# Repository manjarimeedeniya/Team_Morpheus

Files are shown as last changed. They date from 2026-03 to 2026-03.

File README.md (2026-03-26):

# Weighing Scale Using Load Cells

**EN2091 Analog Project** — Department of Electronic and Telecommunication Engineering, University of Moratuwa, Sri Lanka

---

## 👥 Team Morpheus 

| Name | GitHub Link |
|---|---|
| Gunarathne K.T.M.B | https://github.com/ThidaswinGunarathna |
| Jayaweera N.S | https://github.com/NisalJayaweera |
| Meedeniya M.M.H | https://github.com/manjarimeedeniya |
| Ranawaka R.A.C.D | https://github.com/chaniruranawaka |

---

## 📋 Project Overview

An electronic weighing scale designed and implemented using a **strain gauge load cell**. The system captures the low-level differential voltage produced by the load cell, amplifies and filters it through an analog signal conditioning circuit, and displays the corresponding weight on a **16×2 LCD screen** via an ESP32 microcontroller.

**Key Specifications:**
- Maximum measuring capacity: **10 kg**
- Power input: **230V AC mains**
- Full-scale output voltage: **3V** (at 10 kg)
- Display: **16×2 LCD** (via I²C interface)
- Microcontroller: **ESP-WROOM-32E (ESP32)**

---

## 📸 Final Product
<p align="center">
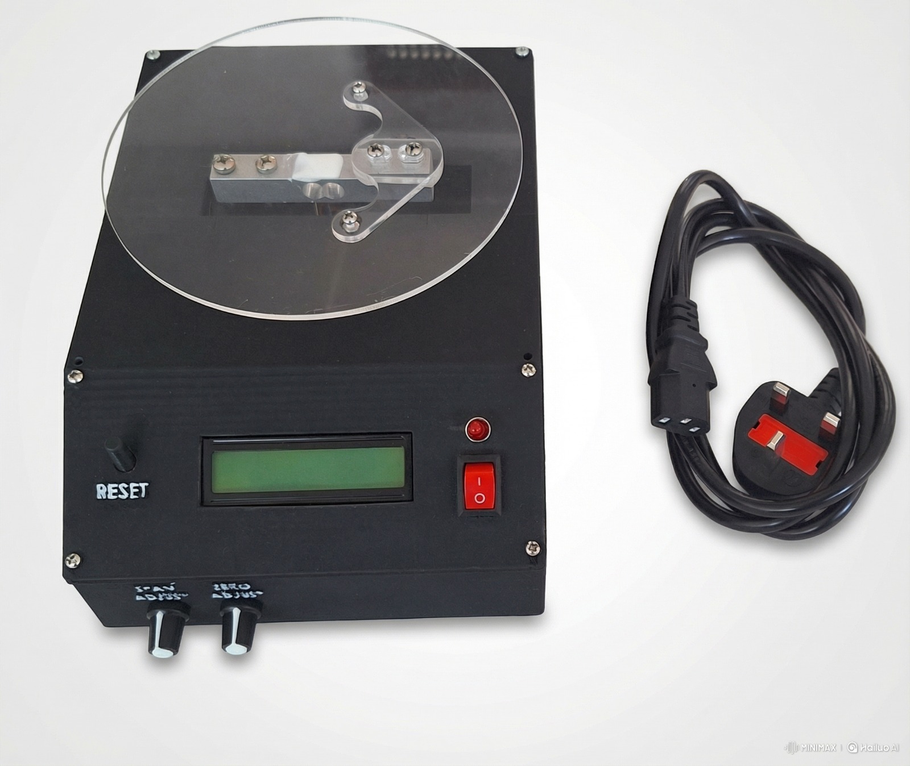
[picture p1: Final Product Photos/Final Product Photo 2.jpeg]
Weighing Scale - Final Product
  
</p>

---

## 🏗️ System Architecture

```
230V AC Supply
      │
      ▼
Step-Down Transformer (230V → 13.5V AC)
      │
      ▼
Power Supply Circuit (Delon Doubler + Regulators)
      │
      ├──► +12V, -12V (for op-amps & load cell excitation)
      ├──► +5V  (for LCD)
      └──► +3.3V (for ESP32)

Load Cell (Wheatstone Bridge)
      │
      ▼
INA114 Instrumentation Amplifier (Gain ≈ 100)
      │
      ▼
Zero Adjust Circuit (TL084 op-amp + potentiometer)
      │
      ▼
Span Adjust Circuit (TL084 op-amp, variable gain)
      │
      ▼
3rd Order Sallen-Key Low-Pass Filter (10 Hz cutoff, TL072)
      │
      ▼
ESP32 ADC → Weight Calculation → 16×2 LCD Display
```

---

## ⚙️ Circuit Design

### Load Cell
- Type: Strain-gauge based, Wheatstone bridge configuration
- Capacity: 20 kg (used up to 10 kg)
- Rated output: 2.0 ± 0.15 mV/V
- Excitation voltage: 12V DC

### Amplifier Circuit
| Stage | Component | Purpose |
|---|---|---|
| Instrumentation Amplifier | INA114 | Amplifies differential load cell output (gain ≈ 100), high CMRR (~115 dB) |
| Zero Adjust | TL084 + 100kΩ potentiometer | Cancels offset voltage at zero load |
| Span Adjust | TL084 + 100kΩ potentiometer | Calibrates full-scale output to 3V at 10 kg |
| Low-Pass Filter | TL072 (3rd order Sallen-Key) | Cuts off noise above 10 Hz |

### Power Supply Circuit
| Regulator | Output | Powers |
|---|---|---|
| LM7812 | +12V | Load cell, INA114, op-amps |
| LM7912 | -12V | Op-amps (dual supply) |
| LM7805 | +5V | LCD display |
| AMS1117 | +3.3V | ESP32 chip |

The Delon Doubler circuit is used to generate the dual-supply (±) voltage from the single-rail transformer output.

---

## 🧰 Components List

### Amplifier Circuit
| Component | Quantity |
|---|---|
| INA114 Instrumentation Amplifier IC | 1 |
| TL084 Quad Op-Amp IC | 1 |
| TL072 Dual Op-Amp IC | 1 |
| 470Ω Resistor | 1 |
| 10kΩ Resistors | 8 |
| 100kΩ Resistor | 1 |
| 110kΩ Resistor | 1 |
| 11kΩ Resistor | 1 |
| 33kΩ Resistor | 1 |
| 100kΩ Variable Resistors (Potentiometers) | 2 |
| 0.1µF Capacitors | 5 |
| 0.68µF Capacitor | 1 |
| 1.5µF Capacitor | 1 |
| Push Buttons | 2 |
| JST Wire Connectors 2.54mm (4-pin) | 3 |
| JST Wire Connectors 2.54mm (5-pin) | 1 |

### Power Supply Circuit
| Component | Quantity |
|---|---|
| 230V AC to 13.5V AC Step-Down Transformer | 1 |
| 1N4007 Diodes | 2 |
| 50V 1000µF Capacitors | 2 |
| 50V 470µF Capacitors | 2 |
| 50V 100µF Capacitors | 2 |
| 50V 10µF Capacitors | 2 |
| LM7812 +12V Regulator | 1 |
| LM7912 -12V Regulator | 1 |
| LM7805 +5V Regulator | 1 |
| AMS1117 3.3V Regulator | 1 |
| Switch | 1 |
| LED | 1 |
| JST Wire Connectors 2.54mm (2-pin) | 3 |
| JST Wire Connectors 2.54mm (5-pin) | 1 |

### Other Components
| Component | Quantity |
|---|---|
| 20kg Strain-Gauge Load Cell | 1 |
| ESP-WROOM-32E Microcontroller | 1 |
| 16×2 LCD Display | 1 |
| IIC/I²C Serial Interface Module for LCD | 1 |
| 3-pin AC Power Base | 1 |
| Power Cable | 1 |

---

---

## 🔧 Calibration Procedure

1. **Zero Adjustment** — With no load on the scale, adjust the zero-adjust potentiometer until the LCD reads `0.00 kg`.
2. **Span Adjustment** — Place a known 10 kg reference weight on the platform. Adjust the span-adjust potentiometer until the display reads `10.00 kg`.
3. The system is now calibrated across the full measurement range.

---

## 💻 Firmware

The ESP32 firmware reads the analog voltage output from the signal conditioning circuit via its built-in ADC, applies the calibration mapping, and sends the weight value to the 16×2 LCD over I²C.

**Upload Instructions:**
1. Install the [Arduino IDE](https://www.arduino.cc/en/software) and add ESP32 board support.
2. Install the `LiquidCrystal_I2C` library via the Library Manager.
3. Open `firmware/main.ino`, select your board (`ESP32 Dev Module`) and COM port.
4. Upload the sketch.

---

## 🚧 Challenges Encountered

- **Capacitor availability** — 0.68µF and 1.5µF electrolytic capacitors were unavailable locally. Ceramic equivalents were used, but their lead spacing required manual wire extensions to fit the PCB footprint.
- **Electromagnetic interference** — After full assembly, the amplifier output showed an unexpected ~60V peak-to-peak sine wave. This was traced to electromagnetic radiation from the mains transformer coupling into nearby signal wires. The fix involved additional transformer shielding with a metal plate and shortening signal wire runs.
- **Platform deformation** — The initial wooden weighing platform deformed under load and made contact with the base, introducing measurement errors. It was replaced with a rigid acrylic plate with a larger clearance gap.

---

## 🔭 Future Improvements

- **Battery operation** — Replace mains power with a low-power design for portability.
- **Wireless connectivity** — Add Bluetooth or Wi-Fi (ESP32 already supports this) for remote monitoring and data logging to a mobile app or PC.

---

## 👨‍💼 Contributions

| Member | Contributions |
|---|---|
| Gunarathne K.T.M.B  | ESP32 firmware, LCD integration, soldering, assembly, component selection |
| Jayaweera N.S  | PCB design, soldering, assembly, component selection |
| Meedeniya M.M.H  | Circuit design, enclosure design, assembly, component selection |
| Ranawaka R.A.C.D  | Enclosure span design, soldering, assembly, component selection |

---

## 🙏 Acknowledgements

We sincerely thank **Dr. Sampath Perera** and supervisor **Mr. Viruthshaan** for their guidance throughout the project. We also appreciate the feedback from **Dr. Jayathu Samarawickrama**, **Dr. Pranjeevan Kulasingham**, **Dr. Wageesha N. Manamperi**, and **Mr. Lathika Wathsara** during the project evaluation. Thanks to the academic and non-academic staff of the ENTC Department, University of Moratuwa, for their support and facilities.

---

## 📚 References

1. INA114 Datasheet — https://www.alldatasheet.com/datasheet-pdf/view/847617/TI1/INA114.html
2. TL084 Datasheet — https://www.alldatasheet.com/datasheet-pdf/view/25385/STMICROELECTRONICS/TL084.html
3. TL072 Datasheet — https://www.alldatasheet.com/datasheet-pdf/view/28775/TI/TL072.html
4. LM7812 Datasheet — https://www.alldatasheet.com/datasheet-pdf/pdf/838008/TI1/LM7812.html

---

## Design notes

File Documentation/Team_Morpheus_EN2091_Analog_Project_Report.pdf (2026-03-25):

## Department of Electronic and Telecommunication Engineering

## University of Moratuwa

## Sri Lanka

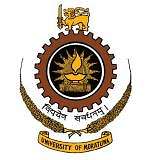
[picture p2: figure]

## EN2091 Analog Project

## Weighing Scale Using Load Cells

## Group 10 - Team Morpheus

Group Members:

### 230203G - Gunarathne K.T.M.B 230300C - Jayaweera N.S 230407K - Meedeniya M.M.H 230526A - Ranawaka R.A.C.D

Date: 11th

### of December 2025

WEIGHING SCALE USING LOAD CELL | GROUP 10
- 2 -

## Abstract

This project presents the design and implementation of an electronic weighing scale using a strain gauge load cell for weight measurement. The low-level differential voltage which is produced by the load cell is proportional to the applied load, and it is amplified using an operational amplifier-based signal conditioning circuit. An active filter is employed to reduce noise and improve measurement stability. The conditioned signal is processed, and the corresponding weight value is displayed on a 16×2 LCD screen through a serial interface. The developed system can measure weights up to 10 kg with satisfactory accuracy. This project demonstrates practical aspects of sensor interfacing, analog signal amplification, noise filtering, and display integration.

- 3 -

## Contents

### 1. Introduction | - 4 -

### 2. System Architecture | - 4 -

Functional Block Diagram | - 4 -
Load Cell | - 4 -
Amplifier Circuit | - 5 -
Power Supply Circuit | - 6 -

### 3. Component Selection | - 7 -

Components for the Amplifier Circuit | - 8 -
Components for the Power Supply Circuit | - 9 -
Other Components | - 9 -

### 4. PCB Design | - 10 -

Amplifier Circuit | - 10 -
Power Supply Circuit | - 11 -

### 5. Enclosure Design | - 12 -

### 6. Challenges Encountered | - 14 -

### 7. Future Works | - 15 -

### 8. Conclusion | - 15 -

### 9. Contribution of Group Members | - 16 -

### 10. Acknowledgement | - 16 -

### 11. References | - 16 -

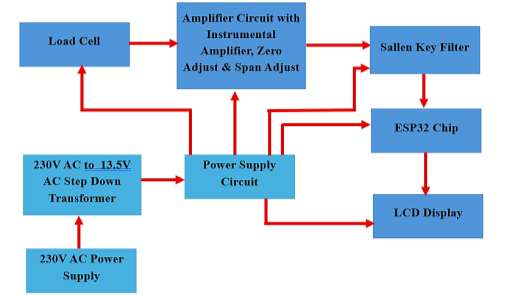
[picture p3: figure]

- 4 -

## Introduction

In this project, an electronic weighing scale is designed and developed using a strain-gauge-based load cell with a maximum measuring capacity of 10 kg. The system operates using a 230 V AC mains power supply. This mains voltage is stepped down to 13.5 V AC through a transformer and then rectified and regulated to provide the required DC voltages for different circuit components. The small electrical signal generated by the load cell is amplified and processed using a microcontroller, which calculates the corresponding weight and displays it on a 16×2 LCD screen. Additionally, a protective enclosure is designed to house all electronic components securely.

## System Architecture

Functional Block Diagram

Figure 1 : Functional Block Diagram

Load Cell

This weighing scale using a strain gauge–based load cell sensor operates by converting the applied mechanical force into an electrical signal
and processing it to obtain a readable weight value.
When an object is placed on the circular platform,
the applied weight is transferred to the load cell. The load cell consists of strain gauges arranged in a Wheatstone bridge (Figure 2)configuration. As
the load is applied, the strain gauges deform
slightly, causing a proportional change in their

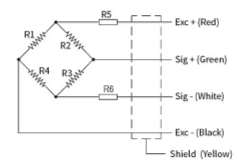
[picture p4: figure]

electrical resistance. This resistance variation | Figure 2 : Wheatstone Bridge
| in Load Cell Sensor

- 5 -

produces a small differential DC voltage signal corresponding to the applied weight. The output signal from the load cell is fed into an amplifier circuit.

Amplifier Circuit
Instrumentation Amplifier

This is the first stage of the amplifier circuit, and when the output from the load cell is fed into the amplifier circuit, this is used to amplify low-level differential voltage output generated by the load cell. In our system this has a gain around 100. Its high input impedance and high CMRR enable

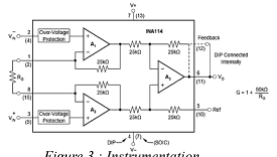
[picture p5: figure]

accurate signal amplification while minimizing noise.

Zero Adjust Circuit
The zero adjust circuit is incorporated after the instrumentation amplifier stage to eliminate offset errors and ensure accurate weight measurement. Even when no load is applied to the load cell, small offsets can appear at the output due to strain gauge mismatch, amplifier input offset voltage, temperature variations, or mechanical stresses. If not corrected, these offsets would cause the weighing scale to display a non-zero value at no load.

In our design, the zero adjustment is implemented
using an operational amplifier (TL084) configured
with a variable reference voltage derived from a potentiometer connected between +12 V and −12
V. The wiper of the potentiometer provides an adjustable DC voltage, which is fed into the summing node of the op-amp through equal-value
resistors (10 kΩ). This arrangement allows a small
positive or negative DC offset to be added to or

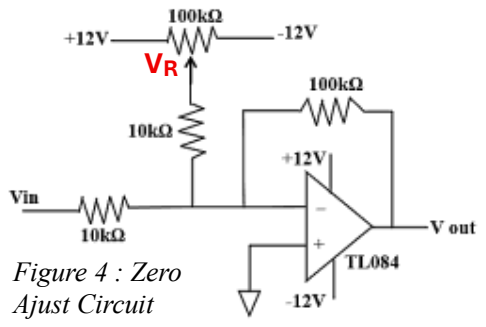
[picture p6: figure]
Figure 4 : Zero Ajust Circuit

subtracted from the amplified load cell signal. By adjusting the potentiometer, the output of this stage can be precisely set to zero when the weighing platform is unloaded.

Equations:

Vin
10×10³ +

VR
10 ×10³ =

Vout
100 ×10³

Vin + VR =

Vout
10

Zero adjust is performed when the load cell is unloaded. So the Vout should become theoritically zero after zzero adjust is performed. So,

VR = −Vin

Figure 3 : Instrumentation Amplifier Circuit Inside the Instrumentation Amplifier IC

- 6 -

Span Adjust Circuit

The span adjust circuit is used to calibrate the gain of the weighing scale system so that the output voltage corresponds accurately to the applied load over the full measurement range. In our design, the span adjustment is implemented using an operational amplifier (TL084) configured with a variable gain. A potentiometer is incorporated in the feedback path of the amplifier, allowing the overall gain of this stage to
be finely adjusted. During calibration, a known
10kg weight is placed on the load cell, and the
potentiometer is adjusted until the system output corresponds to the correct weight value on the display. This ensures that the full-scale output voltage of the signal conditioning circuit accurately represents the maximum rated load of the weighing scale. In our case the full scale output voltage has been chosen as 3V for maximum rated load 10kg, since this output needs to be fed to the microcontroller.
Equation : Vout =

1
20

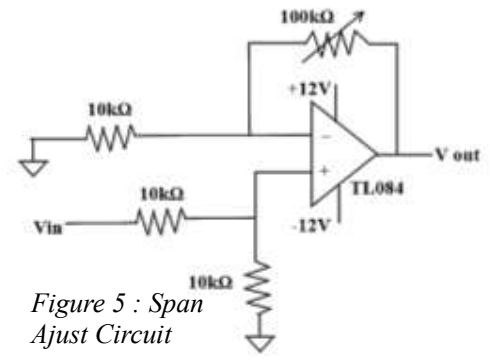
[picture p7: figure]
Figure 5 : Span Ajust Circuit

(Resistance of tℎe variable resistor + 10) Vin

Filter Circuit
In the end of the amplifier circuit, a 3rd order Sallen Key low pass filter with a 10Hz cutoff is implemented. The primary function of this filter
is to allow low-frequency signals corresponding
to actual weight changes to pass through while
attenuating high-frequency noise components. Since weight variations occur slowly, high-frequency signals do not contain useful information and must be removed.

ESP32 Chip & LCD Display

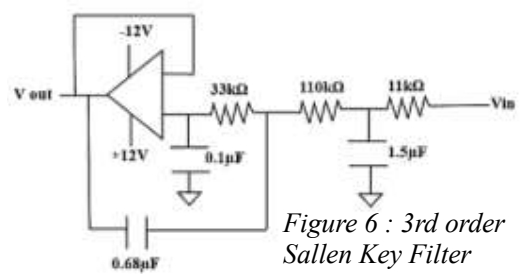
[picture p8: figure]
Figure 6 : 3rd order Sallen Key Filter

The amplified and filtered signal is read by the microcontroller’s analog-to-digital converter. Using the programmed calibration parameters and conversion algorithms, the microcontroller processes the signal and converts it into a corresponding weight value. This calculated weight is then displayed on an LCD screen.

Power Supply Circuit

The 13.5(RMS) V AC output from the transformer is fed to the power supply circuit input. The voltage goes through the Delon Doubler circuit. Here Delon Doubler circuit has been used to get dual supply voltage. Then the regulators regulate the voltage to +12V, -12V, +5V and +3.3V, and then the voltage is distributed to the components.

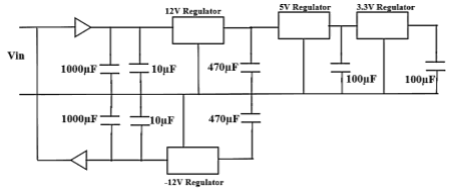
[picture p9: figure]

- 7 -

Figure 7 : Power Supply Circuit

## Component Selection

Components for the Amplifier Circuit | Components for the Power Supply Circuit | Other Components
INA 114 Instrumentation Amplifier – 1 | 230V AC to 13.5 V AC Step Down Transformer | 20kg Load Cell
TL084 OpAmp IC – 1 | 1N4007 Diodes – 2 | ESP-WROOM-32E microcontroller
TL072 OpAmp IC – 1 | 50V 1000µF Capacitors – 2 | 16 x 2 LCD Display
470Ω Resistor – 1 | 50V 470µF Capacitors – 2 | IIC/I2C/TWI/SPI Serial Interface Board Module Port for 1602 LCD Display
100kΩ variable resistors -2 | 50V 100µF Capacitors – 2 | 3 pin AC power base
10kΩ resistors – 8 | 50V 10µF Capacitors – 2 | Power cable
100kΩ resistors – 1 | LM7812 12V Regulator – 1
110kΩ resistors – 1 | LM7912 -12V Regulator – 1
11kΩ resistors – 1 | LM7805 5V Regulator – 1
33kΩ resistors – 1 | AMS1117 3.3V Regulator – 1
0.1µF Capacitors – 5 | Switch
0.68µF Capacitors – 1 | LED
1.5µF Capacitors – 1 | JST Wire connectors 2.54mm with socket 5 pin – 1
Push buttons – 2 | JST Wire connectors 2.54mm with socket 2 pin – 3

JST Wire connectors 2.54mm with socket 4 pin – 3

JST Wire connectors 2.54mm with socket 5 pin – 1

Table 1 : Used Component List

- 8 -

Components for the Amplifier Circuit

INA 114 Instrumentation Amplifier IC

When the Wheatstone bridge of load cell sensor outputs the voltage difference between the two nodes, this instrumentation amplifier is used to amplify only the voltage difference between V+ and V- and rejects everything common to both. According to the datasheet, this has an extremely high common mode rejection ratio which is around 115 dB (1). This has a high input impedance, so loading the bridge of load cell sensor is negligible. Gain of this amplifier can be changed in wide range, so you can choose a better gain. Such characteristics of the amplifier ensure accurate and stable weight measurement.

TL084 OpAmp IC

This is a quad JFET-input operational amplifier IC. This IC reduces the complexity of the PCB, having 4 op amp in one IC. According to the datasheet, since this has a high input impedance and a low input bias current, which is around 65pA, this creates no voltage across the resistors. Because such voltage changes can affect the sensitive signals from the load cell sensor. So, these characteristics help to ensure accurate weight measurement. (2) In our design this is used for the inverting amplifier, zero adjust system and span adjust system.

TL072 OpAmp IC

This is a dual JFET-input operational amplifier that is very commonly used in active filter circuits. In our design this opamp is used for the 3rd order Sallen key filter circuit. Since this has a typical input noise of 18 nV/√Hz, it filters small signals, and low noise prevents corrupting the amplified load-cell output. (3)

470Ω Resistor

This resistor is used to get a nearly 100 gains from the instrumentation amplifier .

100kΩ variable resistors

The span adjusts and zero adjust circuits are mainly controlled using these resistors. For this resistance, a big current does not flow through these resistors. In the zero adjust, if the resistor values are very low, it will load the opamp node, and then voltage will be pulled strongly, there will be sudden drastic changes in voltage when performing calculations and calibration will be unstable. If resistance is too large, thermal drift increases and becomes noisy. In the span adjust, if the resistance of the variable resistor is too low, it will be closer

- 9 -

to the other resistor values in the circuit and will high affect to the change of the gain. But for this value amplifier stays linear and the calibration becomes more stable.

Components for the Power Supply Circuit

230V AC to 13.5 V AC Step Down Transformer

For LM7812, the minimum input voltage to maintain linear regulation is 14.6V (4). Mainly to satisfy that requirement, this transformer was selected.

LM7812 12V Regulator & LM7912 negative 12V Regulator

These two regulators are used to give a +12V and -12V input for load cell, INA 114, Zero Adjust, TL084 and TL072 ICs.

LM7805 5V Regulator

This regulator is used to give a +5V input to LCD display.

AMS1117 3.3V Regulator

This regulator is used to give a +3.3V input to esp32 chip.

Other Components

Load Cell

In this project, a strain-gauge type load cell with 20kg maximum capacity was used. Its Rated output is 2.0±0.15(MV/V). Since its recommended excitation voltage is 10~15 V, in our product excitation voltage is given as 12V.

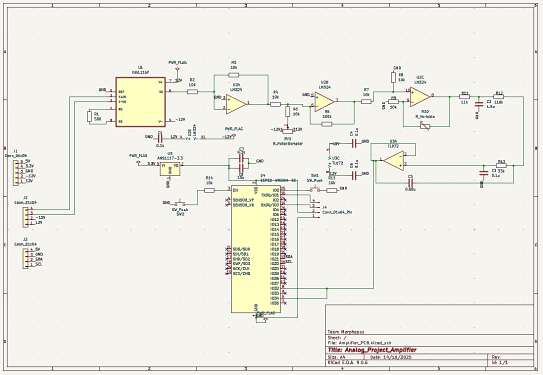
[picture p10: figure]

- 10 -

### 16 x 2 LCD Display

LCD Display is used to display the weight value in the screen. Weight is displayed in kilograms.

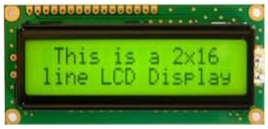
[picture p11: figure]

IIC/I2C/TWI/SPI Serial Interface Board Module Port for 1602 LCD Display

The IIC/I²C/TWI serial interface board for a 1602 LCD is used to enable serial communication between a microcontroller and the LCD display, reducing the number of required I/O pins and simplifying the hardware interface.

## PCB Design

Amplifier Circuit

Schematic & Software Designs

Figure 8 : Amplifier Circuit Schematic

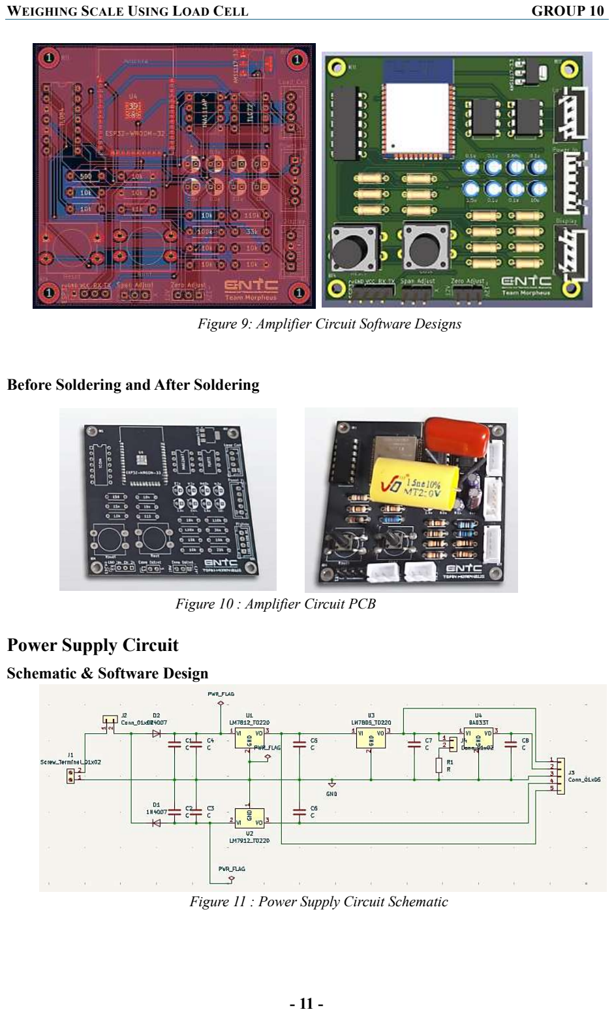
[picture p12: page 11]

- 11 -

Before Soldering and After Soldering

Power Supply Circuit

Schematic & Software Design

Figure 9: Amplifier Circuit Software Designs

Figure 10 : Amplifier Circuit PCB

Figure 11 : Power Supply Circuit Schematic

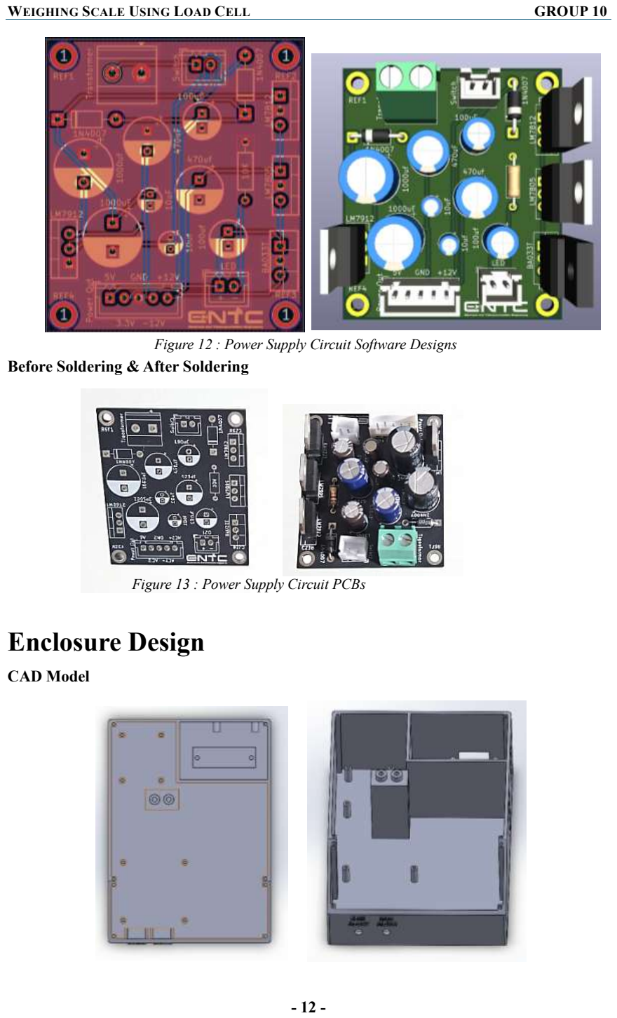
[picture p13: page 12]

- 12 -

Before Soldering & After Soldering

## Enclosure Design

CAD Model

Figure 12 : Power Supply Circuit Software Designs

Figure 13 : Power Supply Circuit PCBs

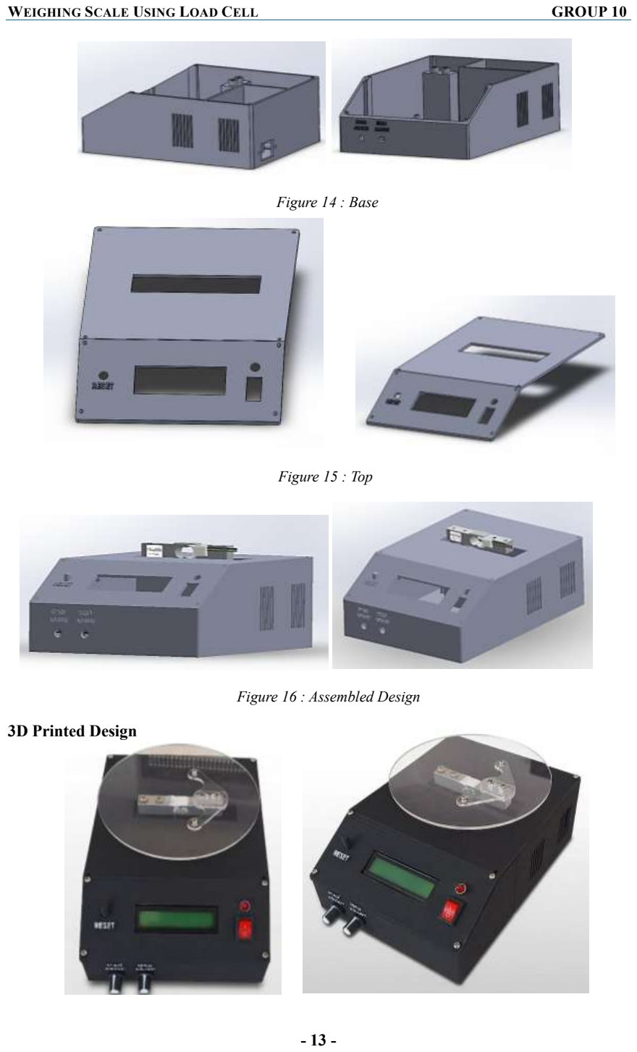
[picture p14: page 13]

- 13 -

3D Printed Design

Figure 14 : Base

Figure 15 : Top

Figure 16 : Assembled Design

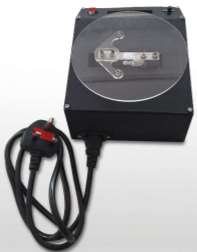
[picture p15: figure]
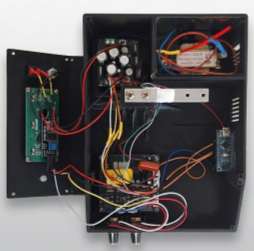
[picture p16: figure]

- 14 -

## Challenges Encountered

- During the implementation of the circuit, 0.68 µF and 1.5 µF electrolytic capacitors were not readily available in the local Sri Lankan market. As an alternative, ceramic capacitors with equivalent capacitance values were selected to proceed with the project without delay. However, the terminal thickness and lead spacing of the ceramic capacitors were not compatible with the PCB design. To overcome this issue, insulated connecting wires were soldered to the capacitor terminals, and these wires were then carefully soldered onto the PCB.
- During the initial PCB testing conducted before assembling the product, the circuit produced the expected output. However, one day prior to the project evaluation, after assembling the complete system and performing the testing again, unexpected issue was observed. The output of the amplifier circuit appeared as a sine wave with an approximately 60 V peak-to-peak voltage, which was abnormal and not expected from the design.

At first, all the circuit connections and solder joints were carefully checked, but no faults were found. Suspecting a defective capacitor, a new PCB was soldered and tested, yet the same issue occurred. When the previously working PCB was powered again using the power supply, it no longer showed the expected voltage variation. At this stage, it was assumed that some components might have been damaged due to the excessive voltage.

As the issue could not be identified through repeated testing, guidance was obtained from Dr. Upeka Premaratne. After examining the setup, he suggested that the problem might be related to the transformer used in the power supply. According to his explanation, electromagnetic radiation from the transformer could have interfered with nearby signal wires, inducing unwanted currents.

Although the transformer had been placed in a separate section of the enclosure, it was advised to further shield the transformer using a metal plate and to minimize and shorten the signal wire lengths to reduce electromagnetic interference. However, due to

Figure 17 : 3D Printed & Assembled Enclosure

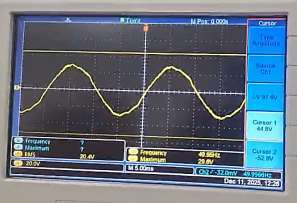
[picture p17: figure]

- 15 -

the use of ceramic capacitors with relatively thick terminals and attached connecting wires, it was difficult to significantly shorten the terminal lengths, and physical size differences further limited the effectiveness of this modification.

- Another challenge was related to the weighing platform structure. Initially, a wooden span was used, but it deformed under higher loads and touched the base of the setup, affecting measurement accuracy. To resolve this, the wooden span was replaced with an acrylic plate, and the gap between the platform and the base was increased to ensure that the load cell could bend freely without contacting any surface.

## Future Works

1.This design can be optimized for battery operation by using a low power component making the system portable.
2.Adding Bluetooth or Wi-Fi connectivity would allow wireless data transmission to a mobile phone or computer for monitoring and record keeping.

## Conclusion

In this project, an electronic weighing scale was successfully designed and implemented using a strain gauge load cell. The very small differential output produced by the load cell was amplified using an operational amplifier-based amplifier circuit, and unwanted noise was reduced using an active filter stage. The processed signal was then converted into a readable weight value and displayed clearly on a 16×2 LCD, providing a user-friendly interface. Overall, the project achieved its intended objectives and provided practical exposure to sensor interfacing, analog signal conditioning, and measurement system design.

Figure 18 : 60V(peak-peak) Sine wave that observed

- 16 -

## Contribution of Group Members

230203G Gunarathne K.T.M.B | Coding to display the measured weight using esp32 chip and LCD display, Soldering, Assembly, Component Selection
230300C Jayaweera N.S | PCB Designing, Soldering, Assembly, Component Selection
230407K Meedeniya M.M.H | Circuit Designing, Enclosure Designing, Assembly, Component Selection
230526A Ranawaka R.A.C.D | Enclosure Span Designing, Soldering, Assembly, Component Selection

## Acknowledgement

We would like to sincerely thank Dr. Sampath Perera and our supervisor Mr. Viruthshaan for their guidance, encouragement, and constant support throughout this project.We also appreciate the time and constructive feedback provided by Dr. Jayathu Samarawickrama, Dr. Pranjeevan Kulasingham, and Dr. Wageesha N. Manamperi,Mr. Lathika Wathsara during the evaluation of the project, which greatly helped us to improve its quality.Our heartfelt thanks go to the academic and non-academic staff of the ENTC Department for their assistance and for providing the necessary facilities during the project period. Finally, we are grateful to all our group members for their teamwork and commitment which were essential to the successful completion of this project.

## References

1. [Online] https://www.alldatasheet.com/datasheet-pdf/view/847617/TI1/INA114.html.
2. [Online] https://www.alldatasheet.com/datasheet-pdf/view/25385/STMICROELECTRONICS/TL084.html.
3. [Online] https://www.alldatasheet.com/datasheet-pdf/view/28775/TI/TL072.html.
4. [Online] https://www.alldatasheet.com/datasheet-pdf/pdf/838008/TI1/LM7812.html.

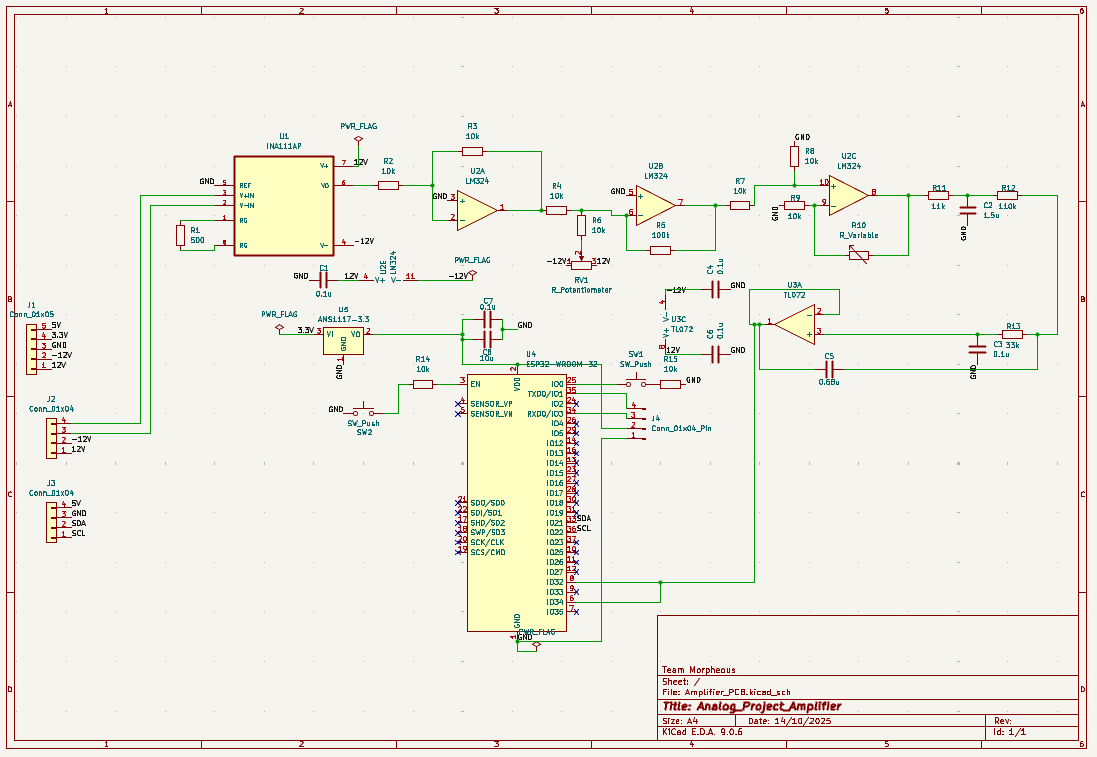
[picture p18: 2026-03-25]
PCB Files/Photos/Amplifier Schematic.png

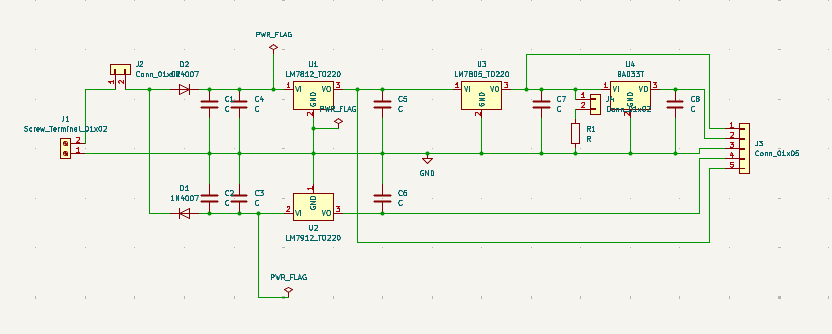
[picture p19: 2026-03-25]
PCB Files/Photos/Power Supply Schematic.png

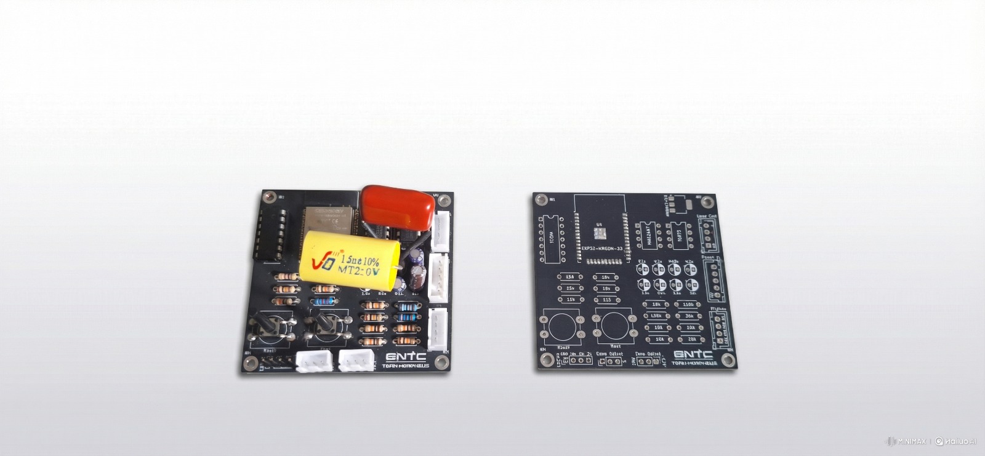
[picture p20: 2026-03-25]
PCB Files/Photos/Amplifier Circuit PCB.jpeg

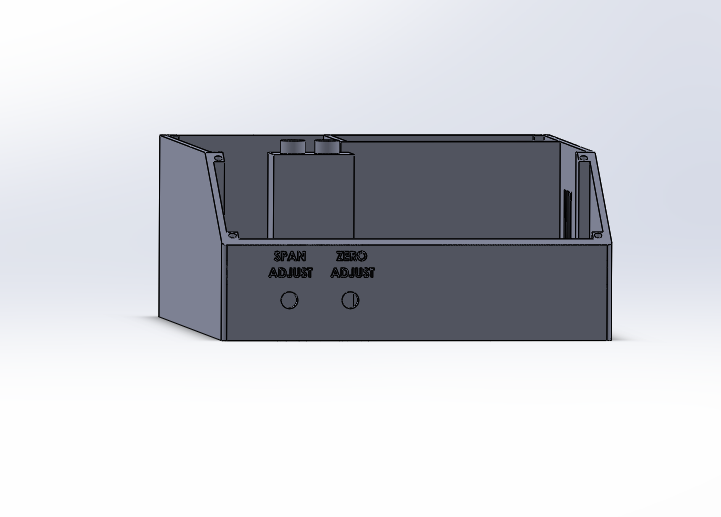
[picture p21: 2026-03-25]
Enclosure Files/Photos/Bottom_5 from SolidWorks.png

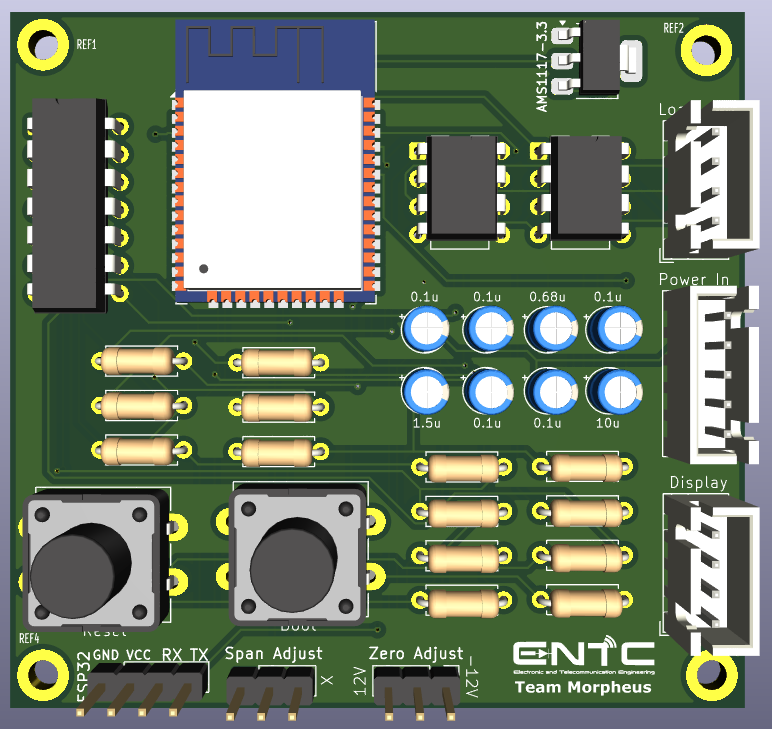
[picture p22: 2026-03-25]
PCB Files/Photos/Amplifier PCB 3D.png

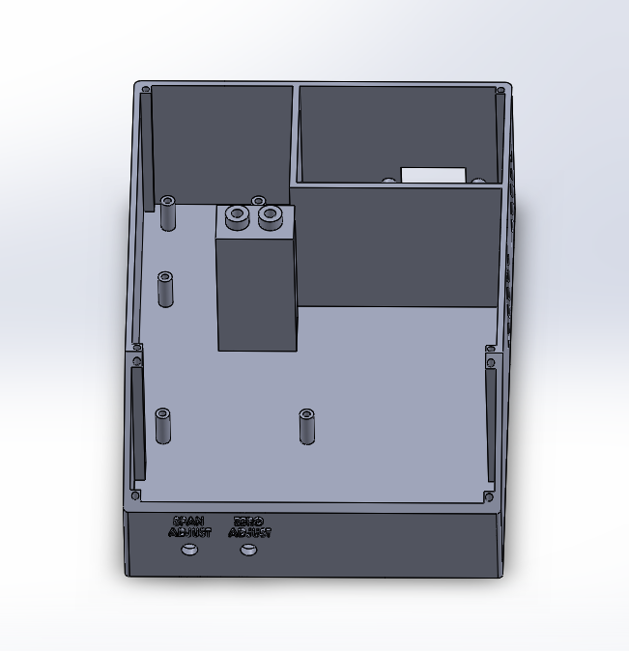
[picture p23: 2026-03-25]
Enclosure Files/Photos/Bottom_1 from SolidWorks.png

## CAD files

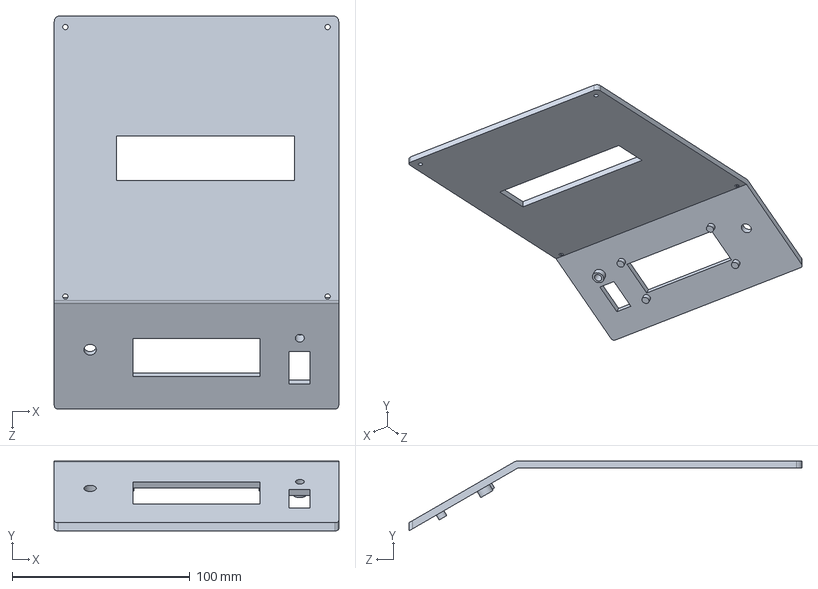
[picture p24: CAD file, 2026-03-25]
Enclosure Files/Top.SLDPRT
160.0 x 39.2 x 221.0 mm

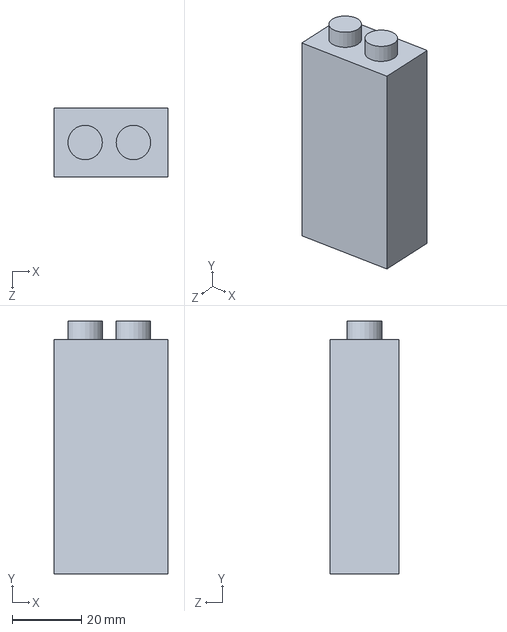
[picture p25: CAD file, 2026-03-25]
Enclosure Files/Loadcell Stand.SLDPRT
33.0 x 73.3 x 20.0 mm

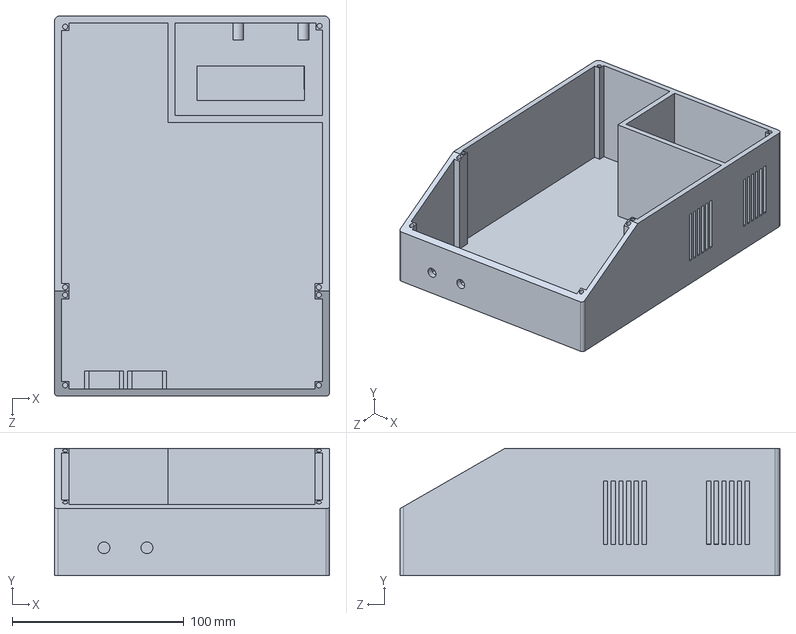
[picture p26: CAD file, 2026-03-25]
Enclosure Files/Base.SLDPRT
160.0 x 74.0 x 221.0 mm

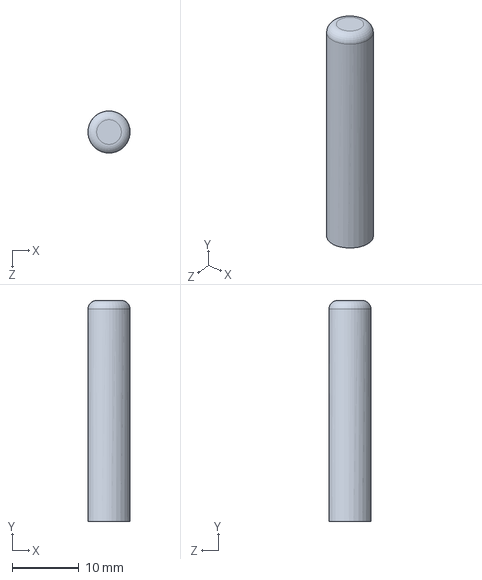
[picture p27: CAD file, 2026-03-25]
Enclosure Files/Tactile Switch Cap.SLDPRT
6.29 x 33.0 x 6.30 mm

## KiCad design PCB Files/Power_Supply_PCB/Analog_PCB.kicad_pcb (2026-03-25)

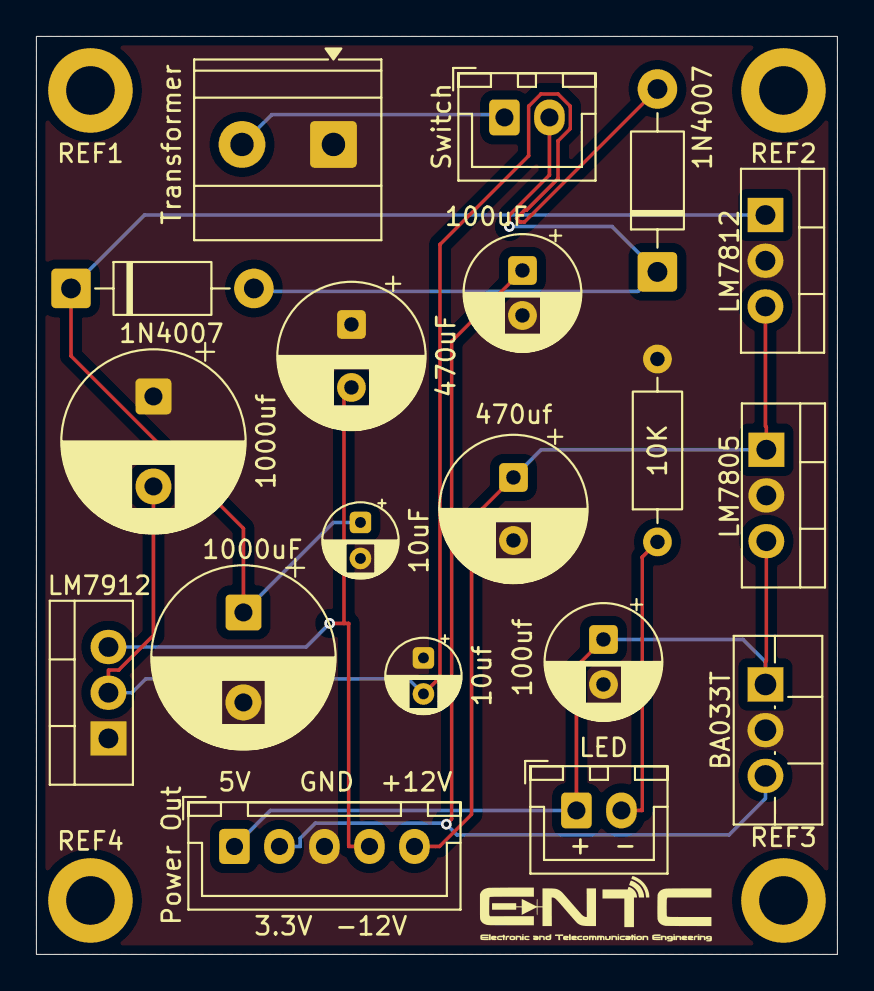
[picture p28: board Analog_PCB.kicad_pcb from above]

Board: 2 copper layers, 44.5 x 51.0 mm, 24 parts (0 on the bottom side), 10 nets.

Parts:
1N4007: 1N4007; D_DO-41_SOD81_P10.16mm_Horizontal
10K: R; R_Axial_DIN0207_L6.3mm_D2.5mm_P10.16mm_Horizontal
10uF, 10uf: C; CP_Radial_D4.0mm_P2.00mm
100uF, 100uf: C; CP_Radial_D6.3mm_P2.50mm
470uF, 470uf: C; CP_Radial_D8.0mm_P3.50mm
1000uF, 1000uf: C; CP_Radial_D10.0mm_P5.00mm
BA033T: BA033T; TO-220F-3_Vertical
D2: 1N4007; D_DO-41_SOD81_P10.16mm_Horizontal
LED: Conn_01x02; JST_XH_B2B-XH-A_1x02_P2.50mm_Vertical
LM7805: LM7805_TO220; TO-220-3_Vertical
LM7812: LM7812_TO220; TO-220-3_Vertical
LM7912: LM7912_TO220; TO-220-3_Vertical
Power Out: Conn_01x05; JST_XH_B5B-XH-A_1x05_P2.50mm_Vertical
REF1, REF2, REF3, REF4: MountingHole_2.7mm_M2.5_DIN965_Pad
Switch: Conn_01x02; JST_XH_B2B-XH-A_1x02_P2.50mm_Vertical
Team Morpheus: LOGO; ENTC_Logo
Transformer: Screw_Terminal_01x02; TerminalBlock_Phoenix_MKDS-1,5-2-5.08_1x02_P5.08mm_Horizont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

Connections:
GND: 10K.2, 10uF.2, 10uf.1, 100uF.2, 100uf.2, 470uF.1, 470uf.2, 1000uF.2, 1000uf.1, BA033T.2 (GND), LM7805.2 (GND), LM7812.2 (GND), LM7912.1 (GND), Power Out.3, Transformer.1
unnamed: 1N4007.2 (A), 10uf.2, 1000uf.2, LM7912.2 (VI)
unnamed: 1N4007.1 (K), D2.2 (A), Switch.2
unnamed: 10uF.1, 1000uF.1, D2.1 (K), LM7812.1 (VI)
unnamed: Switch.1, Transformer.2
unnamed: 100uf.1, BA033T.1 (VI), LED.1, LM7805.3 (VO), Power Out.1
unnamed: 100uF.1, BA033T.3 (VO), Power Out.2
unnamed: 470uF.2, LM7912.3 (VO), Power Out.4
unnamed: 470uf.1, LM7805.1 (VI), LM7812.3 (VO), Power Out.5
unnamed: 10K.1, LED.2

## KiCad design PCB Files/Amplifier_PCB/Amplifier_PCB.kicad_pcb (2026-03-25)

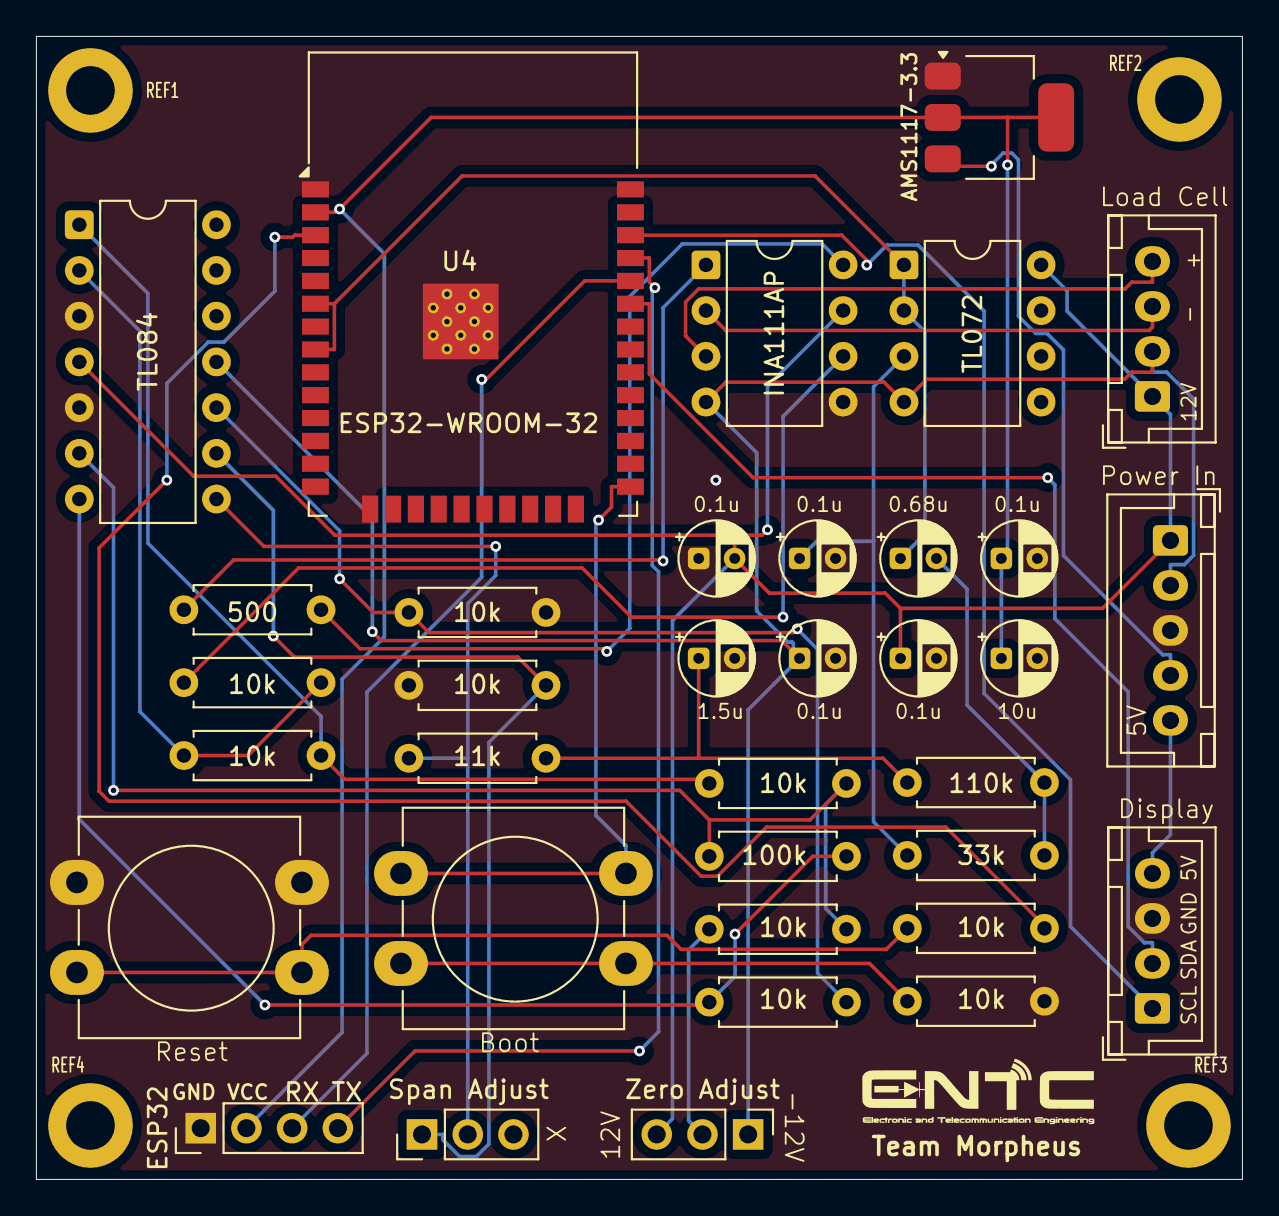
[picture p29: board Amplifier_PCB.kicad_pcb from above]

Board: 2 copper layers, 67.0 x 63.5 mm, 40 parts (0 on the bottom side), 31 nets.

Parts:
10k, 10k#2, 10k#3, 10k#4, 10k#5, 33k, 110k: 10k; R_Axial_DIN0207_L6.3mm_D2.5mm_P7.62mm_Horizontal
100k: 100k; R_Axial_DIN0207_L6.3mm_D2.5mm_P7.62mm_Horizontal
C1, C3, C4, C6, C7: 0.1u; CP_Radial_D4.0mm_P2.00mm
C2: 1.5u; CP_Radial_D4.0mm_P2.00mm
C5: 0.68u; CP_Radial_D4.0mm_P2.00mm
C8: 10u; CP_Radial_D4.0mm_P2.00mm
ESP32: GND; PinHeader_1x04_P2.54mm_Vertical
J1: Conn_01x05; JST_XH_B5B-XH-A_1x05_P2.50mm_Vertical
J2, J3: Conn_01x04; JST_XH_B4B-XH-A_1x04_P2.50mm_Vertical
R1: 500; R_Axial_DIN0207_L6.3mm_D2.5mm_P7.62mm_Horizontal
R2, R3, R8, R9: 10k; R_Axial_DIN0207_L6.3mm_D2.5mm_P7.62mm_Horizontal
R11: 11k; R_Axial_DIN0207_L6.3mm_D2.5mm_P7.62mm_Horizontal
REF1, REF2, REF3, REF4: MountingHole_2.7mm_M2.5_DIN965_Pad
SW1, SW2: SW_Push; SW_PUSH-12mm_Wuerth-430476085716
Span Adjust: R_Variable; PinHeader_1x03_P2.54mm_Vertical
Team Morpheus: LOGO; ENTC_Logo
U1: INA111AP; DIP-8_W7.62mm
U2: TL084; DIP-14_W7.62mm
U3: TL072; DIP-8_W7.62mm
U4: ESP32-WROOM-32
U5: AMS1117-3.3; SOT-223-3_TabPin2
Zero Adjust: R_Potentiometer; PinHeader_1x03_P2.54mm_Vertical

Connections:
/3.3V: J1.4, U5.3 (VI)
/5V: J1.5, J3.4
/12V: C1.2, C6.1, J1.1, J2.1, U1.7 (V+), U2.4 (V+), U3.8 (V+), Zero Adjust.3
/-12V: C4.1, J1.2, J2.2, U1.4 (V-), U2.11 (V-), U3.4 (V-), Zero Adjust.1
/GND: 10k#4.2, C1.1, C2.2, C3.2, C4.2, C6.2, C7.2, C8.2, ESP32.1, J1.3, J3.3, R8.2, R9.1, SW2.1, U1.5 (REF), U2.3 (+), U2.5 (+), U4.1 (GND), U4.15 (GND), U4.38 (GND), U4.39 (GND), U5.1 (GND)
/SCL: J3.1, U4.36 (IO22)
/SDA: J3.2, U4.33 (IO21)
unnamed: 110k.1, C2.1, R11.2
unnamed: 33k.2, 110k.2, C5.2
unnamed: J2.3, U1.2 (V-IN)
unnamed: J2.4, U1.3 (V+IN)
unnamed: C7.1, C8.1, ESP32.2, U4.2 (VDD), U5.2 (VO)
unnamed: ESP32.3, U4.34 (RXD0/IO3)
unnamed: ESP32.4, U4.35 (TXD0/IO1)
unnamed: R1.1, U1.1 (RG)
unnamed: R1.2, U1.8 (RG)
unnamed: 10k#3.1, R3.2, U2.1
unnamed: 10k.1, 100k.2, U2.7
unnamed: 10k#5.1, Zero Adjust.2
unnamed: R11.1, Span Adjust.2, U2.8
unnamed: 10k#2.1, SW2.2
unnamed: 10k#4.1, SW1.2
unnamed: R2.1, U1.6 (VO)
unnamed: R2.2, R3.1, U2.2 (-)
unnamed: 10k#3.2, 10k#5.2, 100k.1, U2.6 (-)
unnamed: 10k.2, R8.1, U2.10 (+)
unnamed: R9.2, Span Adjust.1, U2.9 (-)
unnamed: 33k.1, C3.1, U3.3 (+)
unnamed: C5.1, U3.1, U3.2 (-), U4.6 (IO34), U4.8 (IO32)
unnamed: 10k#2.2, U4.3 (EN)
unnamed: SW1.1, U4.25 (IO0)

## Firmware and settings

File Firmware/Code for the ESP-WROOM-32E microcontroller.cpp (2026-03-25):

#include <Wire.h>
#include <LiquidCrystal_I2C.h>
#include <EEPROM.h>

LiquidCrystal_I2C lcd(0x27, 16, 2);

const int ANALOG_PIN = A0;

const int CAL_POINTS = 11;
float calibrationWeights[CAL_POINTS] =
  {0, 1, 2, 3, 4, 5, 6, 7, 8, 9, 10};
float calibrationVolts[CAL_POINTS];

const int NUM_SAMPLES = 20;

const int EEPROM_MAGIC_ADDR = 0;
const int EEPROM_DATA_START = 1;
const byte EEPROM_MAGIC_VALUE = 0x5A;

void setup() {
  Serial.begin(9600);
  lcd.init();
  lcd.backlight();

  if (EEPROM.read(EEPROM_MAGIC_ADDR) == EEPROM_MAGIC_VALUE) {
    loadCalibrationFromEEPROM();
    lcd.clear();
    lcd.setCursor(0, 0);
    lcd.print("Loaded calib");
    lcd.setCursor(0, 1);
    lcd.print("from EEPROM");
    delay(2000);
  } else {
    calibrateAllPoints();
    saveCalibrationToEEPROM();
    lcd.clear();
    lcd.setCursor(0, 0);
    lcd.print("Calib saved");
    lcd.setCursor(0, 1);
    lcd.print("to EEPROM");
    delay(2000);
  }
  lcd.clear();
}

void loop() {
  float v = readVoltage();
  float w = calculateWeight(v);

  lcd.setCursor(0, 0);
  lcd.print("W: ");
  lcd.print(w, 2);
  lcd.print(" kg   ");

  lcd.setCursor(0, 1);
  lcd.print("V: ");
  lcd.print(v, 3);
  lcd.print(" V   ");

  Serial.print("Weight: ");
  Serial.print(w, 2);
  Serial.print(" kg, V=");
  Serial.println(v, 3);

  delay(500);
}

float readVoltage() {
  long total = 0;
  for (int i = 0; i < NUM_SAMPLES; i++) {
    total += analogRead(ANALOG_PIN);
    delay(5);
  }
  float avg = total / (float)NUM_SAMPLES;
  float voltage = avg * (5.0 / 1023.0);
  return voltage;
}

void calibrateAllPoints() {
  for (int i = 0; i < CAL_POINTS; i++) {
    lcd.clear();
    lcd.setCursor(0, 0);
    lcd.print("Place ");
    lcd.print(calibrationWeights[i], 0);
    lcd.print(" kg");

    lcd.setCursor(0, 1);
    lcd.print("Press key PC");
    waitForSerial();

    delay(1000);
    calibrationVolts[i] = readVoltage();

    Serial.print("Cal ");
    Serial.print(calibrationWeights[i], 0);
    Serial.print(" kg -> ");
    Serial.print(calibrationVolts[i], 4);
    Serial.println(" V");
  }
}

void saveCalibrationToEEPROM() {
  int addr = EEPROM_DATA_START;
  for (int i = 0; i < CAL_POINTS; i++) {
    float v = calibrationVolts[i];
    byte *p = (byte*)&v;
    for (int b = 0; b < 4; b++) {
      EEPROM.update(addr++, p[b]);
    }
  }
  EEPROM.update(EEPROM_MAGIC_ADDR, EEPROM_MAGIC_VALUE);
}

void loadCalibrationFromEEPROM() {
  int addr = EEPROM_DATA_START;
  for (int i = 0; i < CAL_POINTS; i++) {
    float v;
    byte *p = (byte*)&v;
    for (int b = 0; b < 4; b++) {
      p[b] = EEPROM.read(addr++);
    }
    calibrationVolts[i] = v;
  }
}

float calculateWeight(float v) {
  if (v <= calibrationVolts[0]) return 0.0;

  for (int i = 1; i < CAL_POINTS; i++) {
    if (v <= calibrationVolts[i]) {
      return mapFloat(v,
                      calibrationVolts[i - 1], calibrationVolts[i],
                      calibrationWeights[i - 1], calibrationWeights[i]);
    }
  }

  int last = CAL_POINTS - 1;
  return mapFloat(v,
                  calibrationVolts[last - 1], calibrationVolts[last],
                  calibrationWeights[last - 1], calibrationWeights[last]);
}

void waitForSerial() {
  while (!Serial.available()) {}
  while (Serial.available()) Serial.read();
}

float mapFloat(float x,
               float in_min, float in_max,
               float out_min, float out_max) {
  return (x - in_min) * (out_max - out_min) /
         (in_max - in_min) + out_min;
}
